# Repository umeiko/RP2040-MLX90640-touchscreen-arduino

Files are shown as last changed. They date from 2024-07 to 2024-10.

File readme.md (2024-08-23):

## RP2040热成像计划

电路图可以在[这里找到](https://oshwhub.com/umekoko/re-cheng-xiang_copy)

上位机成像在[这里](https://github.com/umeiko/Thermal-Imaging-Receiver)
- RP2040双核MCU + ST7789屏幕（240 * 280）物理分辨率 + CST816T 触摸IC + MLX90640热成像传感器。
- 引出了UART1，以及 SWD 调试接口。
- 可连接上位机图传。
- 集成卡尔曼滤波算法。

94acdedc4a31000fca7f8e9933caeeaf1839720

3a3f02000d5065bd46c5adb85640058

- 提供了热成像代码，位于`thermal_app`中。
- 提供lvgl示例代码，位于`lvgl_rp2040_example`中。
### 配置环境
- 配置 arduino-pico环境，具体可参考[arduino-pico](https://github.com/earlephilhower/arduino-pico/tree/master)仓库。
- Arduino按照如下参数配置开发板



- 配置好 `TFT_eSPI`屏幕驱动库，版本为`2.5.43`，具体可参考[TFT_eSPI](https://github.com/Bodmer/TFT_eSPI/tree/master)仓库。
- 将`C:\Users\*你自己的名字*\Documents\Arduino\libraries\TFT_eSPI\User_Setup.h`中替换成以下内容：

    ```C
    // ST7789 240 x 280 display with no chip select line
    #define USER_SETUP_ID 18
    #define ST7789_DRIVER 

    #define TFT_WIDTH  240
    #define TFT_HEIGHT 280

    #define CGRAM_OFFSET      // Library will add offsets required
    #define TFT_RGB_ORDER TFT_RGB  // Colour order Red-Green-Blue

    #define TFT_CS 9   // CS
    #define TFT_DC 8   // RX
    #define TFT_RST -1  // No Reset pin
    #define TFT_MOSI 7  // TX
    #define TFT_SCLK 6  // SCK

    #define LOAD_GLCD   
    #define LOAD_FONT2  
    #define LOAD_FONT4 
    #define LOAD_FONT6  
    #define LOAD_FONT7  
    #define LOAD_FONT8  
    #define LOAD_GFXFF  

    #define SMOOTH_FONT
    #define RP2040_PIO_SPI
    #define RP2040_DMA
    #define SPI_FREQUENCY  40000000
    #define SUPPORT_TRANSACTIONS
    ```
- 直接编译上传即可。

## 有问题发ISSUE

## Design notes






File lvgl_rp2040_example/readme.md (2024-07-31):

## LVGL示例

3a3f02000d5065bd46c5adb85640058

### 配置环境
- 配置 arduino-pico环境，具体可参考[arduino-pico](https://github.com/earlephilhower/arduino-pico/tree/master)仓库。
- 配置好 `TFT_eSPI`屏幕驱动库，版本为`2.5.43`，具体可参考[TFT_eSPI](https://github.com/Bodmer/TFT_eSPI/tree/master)仓库。
- 配置好 `lvgl`库，版本为`8.3.11`，具体可参考[lvgl](https://github.com/lvgl/lvgl)仓库。
- 将`C:\Users\*你自己的名字*\Documents\Arduino\libraries\TFT_eSPI\User_Setup.h`中替换成以下内容：

    ```C
    // ST7789 240 x 280 display with no chip select line
    #define USER_SETUP_ID 18
    #define ST7789_DRIVER 

    #define TFT_WIDTH  240
    #define TFT_HEIGHT 280

    #define CGRAM_OFFSET      // Library will add offsets required
    #define TFT_RGB_ORDER TFT_RGB  // Colour order Red-Green-Blue

    #define TFT_CS 9   // CS
    #define TFT_DC 8   // RX
    #define TFT_RST -1  // No Reset pin
    #define TFT_MOSI 7  // TX
    #define TFT_SCLK 6  // SCK

    #define LOAD_GLCD   
    #define LOAD_FONT2  
    #define LOAD_FONT4 
    #define LOAD_FONT6  
    #define LOAD_FONT7  
    #define LOAD_FONT8  
    #define LOAD_GFXFF  

    #define SMOOTH_FONT
    #define RP2040_PIO_SPI
    #define RP2040_DMA
    #define SPI_FREQUENCY  40000000
    #define SUPPORT_TRANSACTIONS
    ```
- 将`lv_conf.h`复制到`C:\Users\*你自己的名字*\Documents\Arduino\libraries\`中：
- 直接编译上传即可。

## 有问题发ISSUE

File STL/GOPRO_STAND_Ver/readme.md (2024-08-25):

UW3S @896RI19@5J@LE5`77

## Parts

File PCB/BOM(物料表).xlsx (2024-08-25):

名称 | 数量 | 型号 | 备注 | 购买链接
1K | 4 |  |  | 原装正品0603贴片电阻 1K 标字102 1/10W 精度5% （200只）-淘宝网 (taobao.com) (https://item.taobao.com/item.htm?id=522573302192)
10K | 1 |  |  | 原装正品 0603贴片电阻 10K 标字103 1/10W 精度5% （200只）-淘宝网 (taobao.com) (https://item.taobao.com/item.htm?id=522577284045)
5.1K | 2 |  |  | 原装正品 0603贴片电阻 5.1K 标字512 1/10W 精度5% （200只）-淘宝网 (taobao.com) (https://item.taobao.com/item.htm?id=522573158369&from=cart)
30K | 3 |  |  | 原装正品 0603贴片电阻 30K 标字303 1/10W 精度5% （200只）-淘宝网 (taobao.com) (https://item.taobao.com/item.htm?id=522554259377&from=cart)
51K | 1 |  |  | 原装正品 0603贴片电阻 51K 标字513 1/10W 精度5% （200只）-淘宝网 (taobao.com) (https://item.taobao.com/item.htm?id=522573274162&from=cart)
6.2R | 2 |  |  | 原装正品 0603贴片电阻 6.2R 6.2欧 1/10W 精度±1% （50只）-淘宝网 (taobao.com) (https://item.taobao.com/item.htm?id=525742588948&from=cart)
680K | 1 |  |  | 原装正品 0603贴片电阻 680K 标字684 1/10W 精度5% （200只）-淘宝网 (taobao.com) (https://item.taobao.com/item.htm?id=522573049867&from=cart)
300K | 3 |  |  | 原装正品 0603贴片电阻 300K 标字304 1/10W 精度5% （200只）-淘宝网 (taobao.com) (https://item.taobao.com/item.htm?id=522573437154&from=cart)
22uF | 2 |  |  | 原装0603贴片电容22uF(226)±20% 6.3V X5R CL10A226MQ8NRNE 50只-淘宝网 (taobao.com) (https://item.taobao.com/item.htm?id=626906975873&from=cart)
100nF | 5 |  |  | 0603贴片电容 104P 50V（0.1UF) 100NF 精度±10%（200只）-淘宝网 (taobao.com) (https://item.taobao.com/item.htm?id=522573286298&from=cart)
10uF | 2 |  |  | 原装正品0603贴片电容 10V 10UF ±10% X5R CL10A106KP8NNNC 50只-淘宝网 (taobao.com) (https://item.taobao.com/item.htm?id=537669338432&from=cart)
1uF | 1 |  |  | 【优信电子】0603贴片电容 105M（1UF) 16V 精度±20% (200只）-淘宝网 (taobao.com) (https://item.taobao.com/item.htm?id=522577340017&from=cart)
12pF | 2 |  |  | 原装 0603贴片电容 12pF(120) ±5% 50V NP0 CC0603JRNPO9BN120-淘宝网 (taobao.com) (https://item.taobao.com/item.htm?id=635779002557&from=cart)
10uH | 1 |  |  | 【优信电子】0805贴片电感 10UH ±10% EBLS2012-100K（20只）-淘宝网 (taobao.com) (https://item.taobao.com/item.htm?id=522573385027&from=cart)
4.7uH | 1 |  |  | 252012贴片 4.7uH ±20% SWPA252012S4R7MT 线绕SMD功率电感（5只-淘宝网 (taobao.com) (https://item.taobao.com/item.htm?id=588241056219&from=cart)
MLX90640传感器 | 1 |  |  | 原装正品MLX90640ESF-BAB-000-TU 热敏式图像传感器32x24红外阵列-淘宝网 (taobao.com) (https://item.taobao.com/item.htm?id=672821214850)
AO3401 | 2 |  |  | 贴片 AO3401 SOT-23 MOS管/三极管/场效应管 2.8A（20只）-淘宝网 (taobao.com) (https://item.taobao.com/item.htm?id=522554663865&from=cart)
AO3400 | 1 |  |  | 贴片 AO3400 SOT-23 MOS场效应管 2.5A（20只）-淘宝网 (taobao.com) (https://item.taobao.com/item.htm?id=522574089119&from=cart)
TypeC | 1 |  |  | 全铜 Type-C 3.1插座 16P 沉板1.6/0.8 USB-3.1母座 数据接口-淘宝网 (taobao.com) (https://item.taobao.com/item.htm?id=591365246153&from=cart&skuId=4230575123956)
FPC | 1 | 0.5-1.0H-18P 后翻盖镀金 |  | FFC/FPC连接器0.5-1.0H-4/5/6/8/10/12-40P后翻盖镀金间距0.5mm-淘宝网 (taobao.com) (https://item.taobao.com/item.htm?id=735834856054&from=cart&skuId=5084031056238)
充电芯片 | 1 |  |  | 原装正品 SGM4056-6.8YTDE8G/TR 丝印SG7 TDFN8 锂电池充电管理IC-淘宝网 (taobao.com) (https://item.taobao.com/item.htm?id=584245783298&from=cart)
LED | 1 |  |  | 原装正品 0805贴片LED灯 高亮白色 白光发光二极管正白光（20只）-淘宝网 (taobao.com) (https://item.taobao.com/item.htm?id=522572874608&from=cart)
RP2040 | 1 |  |  | 原装正品 RP2040 LQFN-56 ARM Cortex-M0 133MHz 微控制器芯片-淘宝网 (taobao.com) (https://item.taobao.com/item.htm?id=704705278044)
Flash | 1 |  |  | 原装正品 贴片 W25Q16JVUXIQ UFDFN-8 3V 16M-bit串行闪存芯片-淘宝网 (taobao.com) (https://item.taobao.com/item.htm?id=671657134105)
12Mhz | 1 | 12M 2016无源晶振 4脚 |  | 2016贴片无源晶振12M 16M20M24M25M26M27M32M40M50M19.2M 38.4MHZ-tmall.com天猫 (https://detail.tmall.com/item.htm?id=611704538306&from=cart&skuId=4304314032761)
DCDC | 1 | SGM6036-3.3YUDT6G/TR UTDFN |  | 原装SGM6036-3.3YUDT6G/TR SGM6031-ADJYUDT6G/TR UTDFN贴片-淘宝网 (taobao.com) (https://item.taobao.com/item.htm?id=714214021196&from=cart&skuId=5000729821152)
按钮 | 3 | 2*4*3.5（小侧按） |  | 包邮 轻触开关 侧按键 2*4*3.5/3*6*3.5 小侧按/大侧按 贴片 微动-淘宝网 (taobao.com) (https://item.taobao.com/item.htm?id=740684741262&from=cart&skuId=5282210427438)
触屏模组 | 1 | P169H002-CTP 带电容触摸 |  | 1.69寸全视角IPSTFT彩屏液晶显示屏SPI4L接口ST7789V电容屏触摸屏-淘宝网 (taobao.com) (https://item.taobao.com/item.htm?id=679828186292&from=cart&skuId=5044706070761)
拨片开关 | 1 | SSAJ120100 |  | 日本ALPS SSAJ120100 小薄型拨动开关5脚2档 滑动推进开关 贴片-淘宝网 (taobao.com) (https://item.taobao.com/item.htm?id=641266818120&_u=1uprguofc12)
602530电池 | 1 | 乳白色 602530/500毫安 |  | 602530智能定位儿童电话手表电池3.7V锂电池5V聚合物大容量500mAh-淘宝网 (taobao.com) (https://item.taobao.com/item.htm?id=643350021642&from=cart&skuId=4807232935323)
PCB | 1 |  | 1.6厚度 | rp2040+MLX90640触屏迷你热成像仪 - 嘉立创EDA开源硬件平台 (oshwhub.com) (https://oshwhub.com/umekoko/re-cheng-xiang_copy)
M1.4螺丝 | 4 | M1.4*5 [200只] | 固定PCB | 304不锈钢十字圆头螺丝钉PM盘头螺栓机丝螺钉M1/M1.2/M1.4/M1.6M2 (https://item.taobao.com/item.htm?id=40012193346&from=cart&skuId=5094465275721)
M5*20螺丝 | 1 | M5*20 [20只] | GPRO兼容支架 | 304不锈钢十字圆头螺丝钉PM盘头螺栓机丝螺钉M1/M1.2/M1.4/M1.6M2 (https://item.taobao.com/item.htm?id=40012193346&from=cart&skuId=4814043237375)
M2*5螺丝 | 1 | M2*5 [200只] | GPRO兼容支架 | 304不锈钢十字圆头螺丝钉PM盘头螺栓机丝螺钉M1/M1.2/M1.4/M1.6M2 (https://item.taobao.com/item.htm?id=40012193346&from=cart&skuId=5094465275713)
M3*12螺丝 | 1 | M3*12 [100只] | GPRO兼容支架 | 304不锈钢十字圆头螺丝钉PM盘头螺栓机丝螺钉M1/M1.2/M1.4/M1.6M2 (https://item.taobao.com/item.htm?id=40012193346&from=cart&skuId=4814041545641)

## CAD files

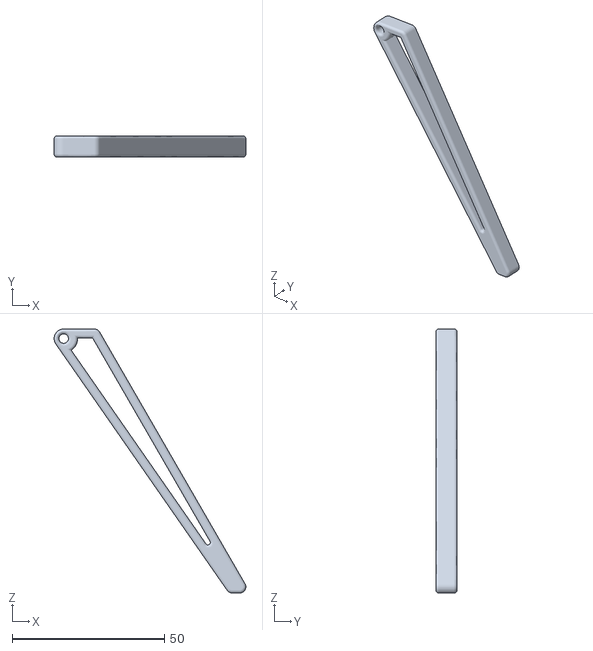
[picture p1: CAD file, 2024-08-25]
STL/GOPRO_STAND_Ver/GO_PRO_TripodLeg_x3.stl
62.9 x 7.00 x 86.6

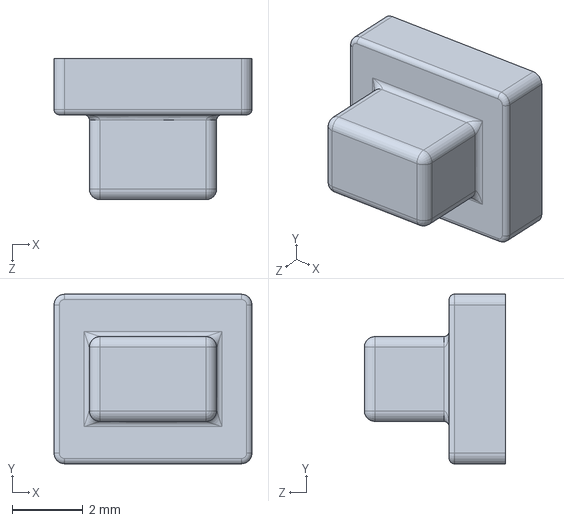
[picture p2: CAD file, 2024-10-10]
STL/on-off-button.SLDPRT
5.60 x 4.80 x 4.00 mm

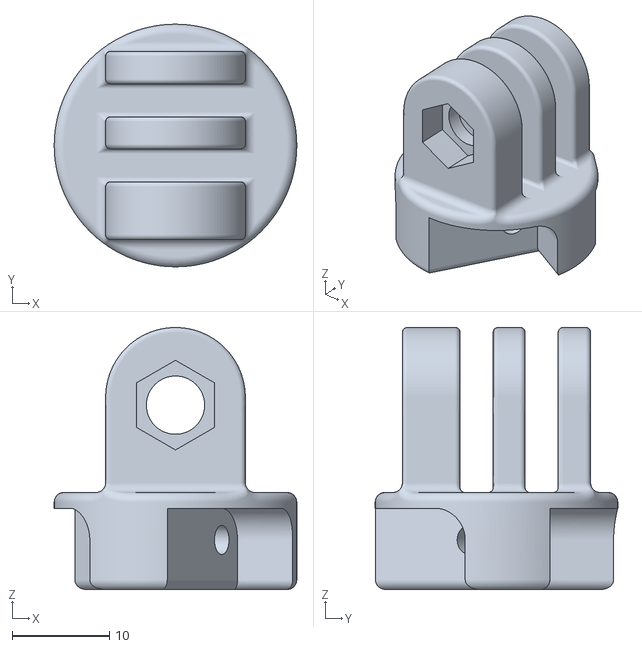
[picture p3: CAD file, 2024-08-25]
STL/GOPRO_STAND_Ver/GO_PRO_TripodHead_x1.stl
25.0 x 25.0 x 27.0

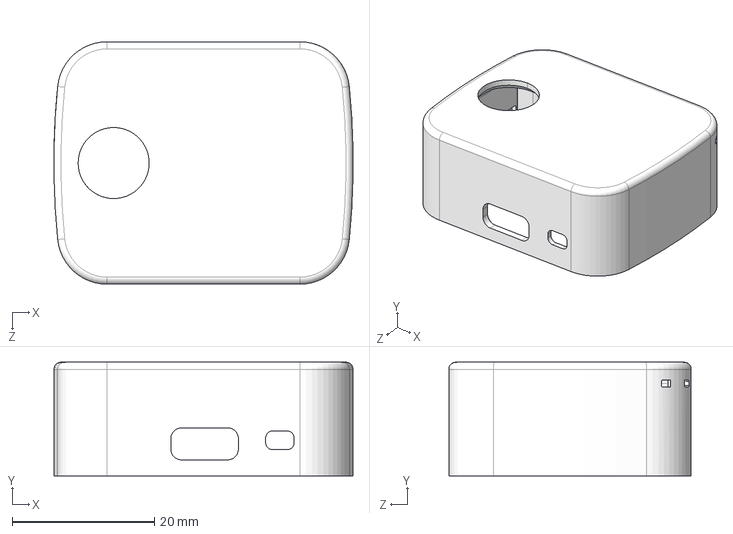
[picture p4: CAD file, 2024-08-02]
STL/shell2040.STEP
42.1 x 16.0 x 34.1 mm

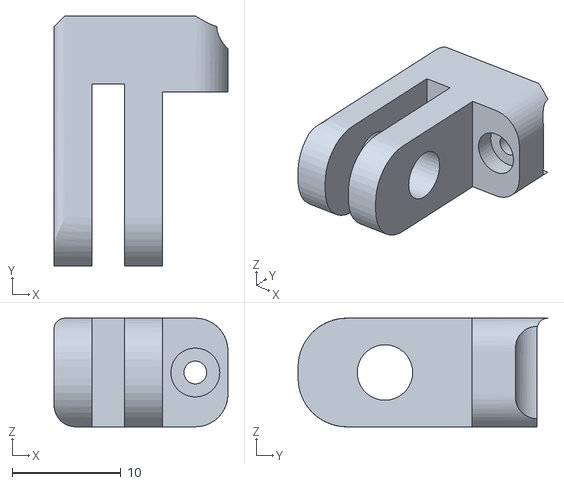
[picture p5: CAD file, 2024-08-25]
STL/GOPRO_STAND_Ver/TransRing_x1.STL
16.0 x 23.0 x 10.0

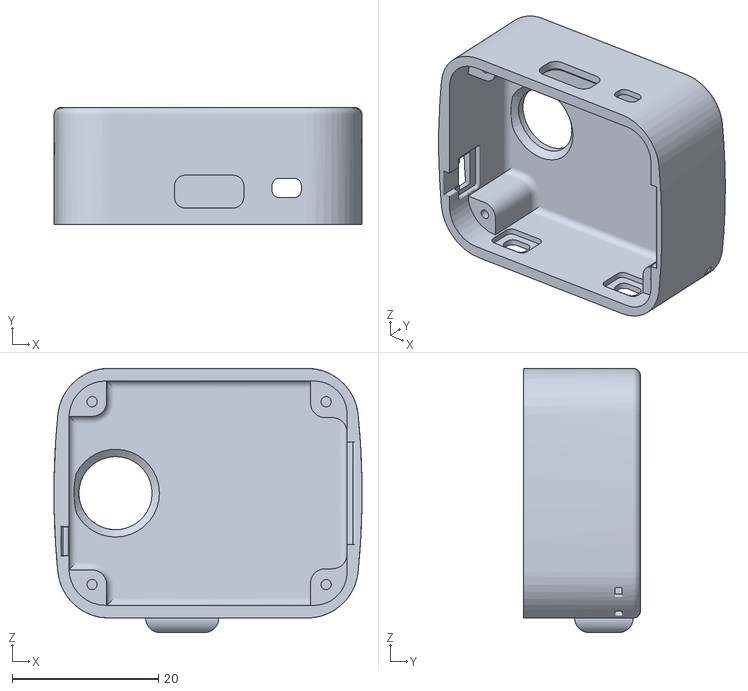
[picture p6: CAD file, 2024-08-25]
STL/GOPRO_STAND_Ver/shell_GOPRO_comp_x1.STL
42.1 x 16.0 x 36.1

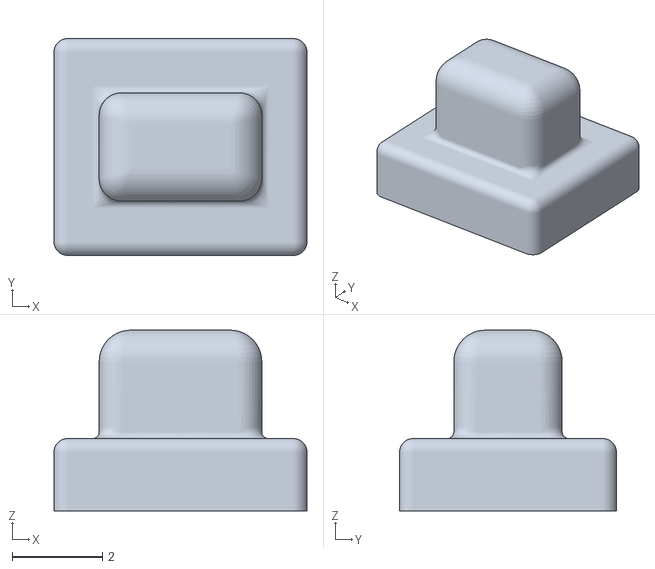
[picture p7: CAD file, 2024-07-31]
STL/switch_x1.STL
5.60 x 4.80 x 4.00

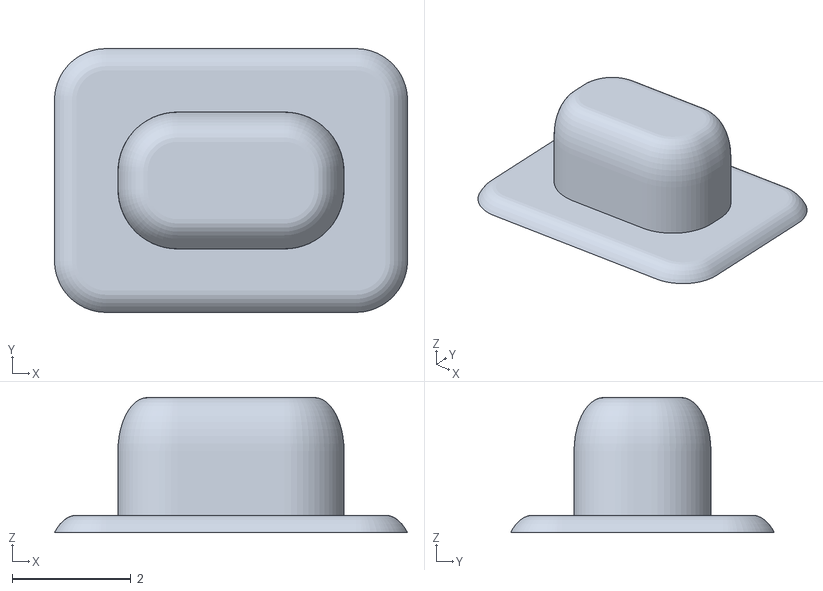
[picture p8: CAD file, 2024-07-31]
STL/GOPRO_STAND_Ver/button_x3.stl
5.93 x 4.43 x 2.27

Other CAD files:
STL/shell.STL
STL/GOPRO_STAND_Ver/switch_x1.STL

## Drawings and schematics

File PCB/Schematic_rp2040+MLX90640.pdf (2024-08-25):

复位
晶振

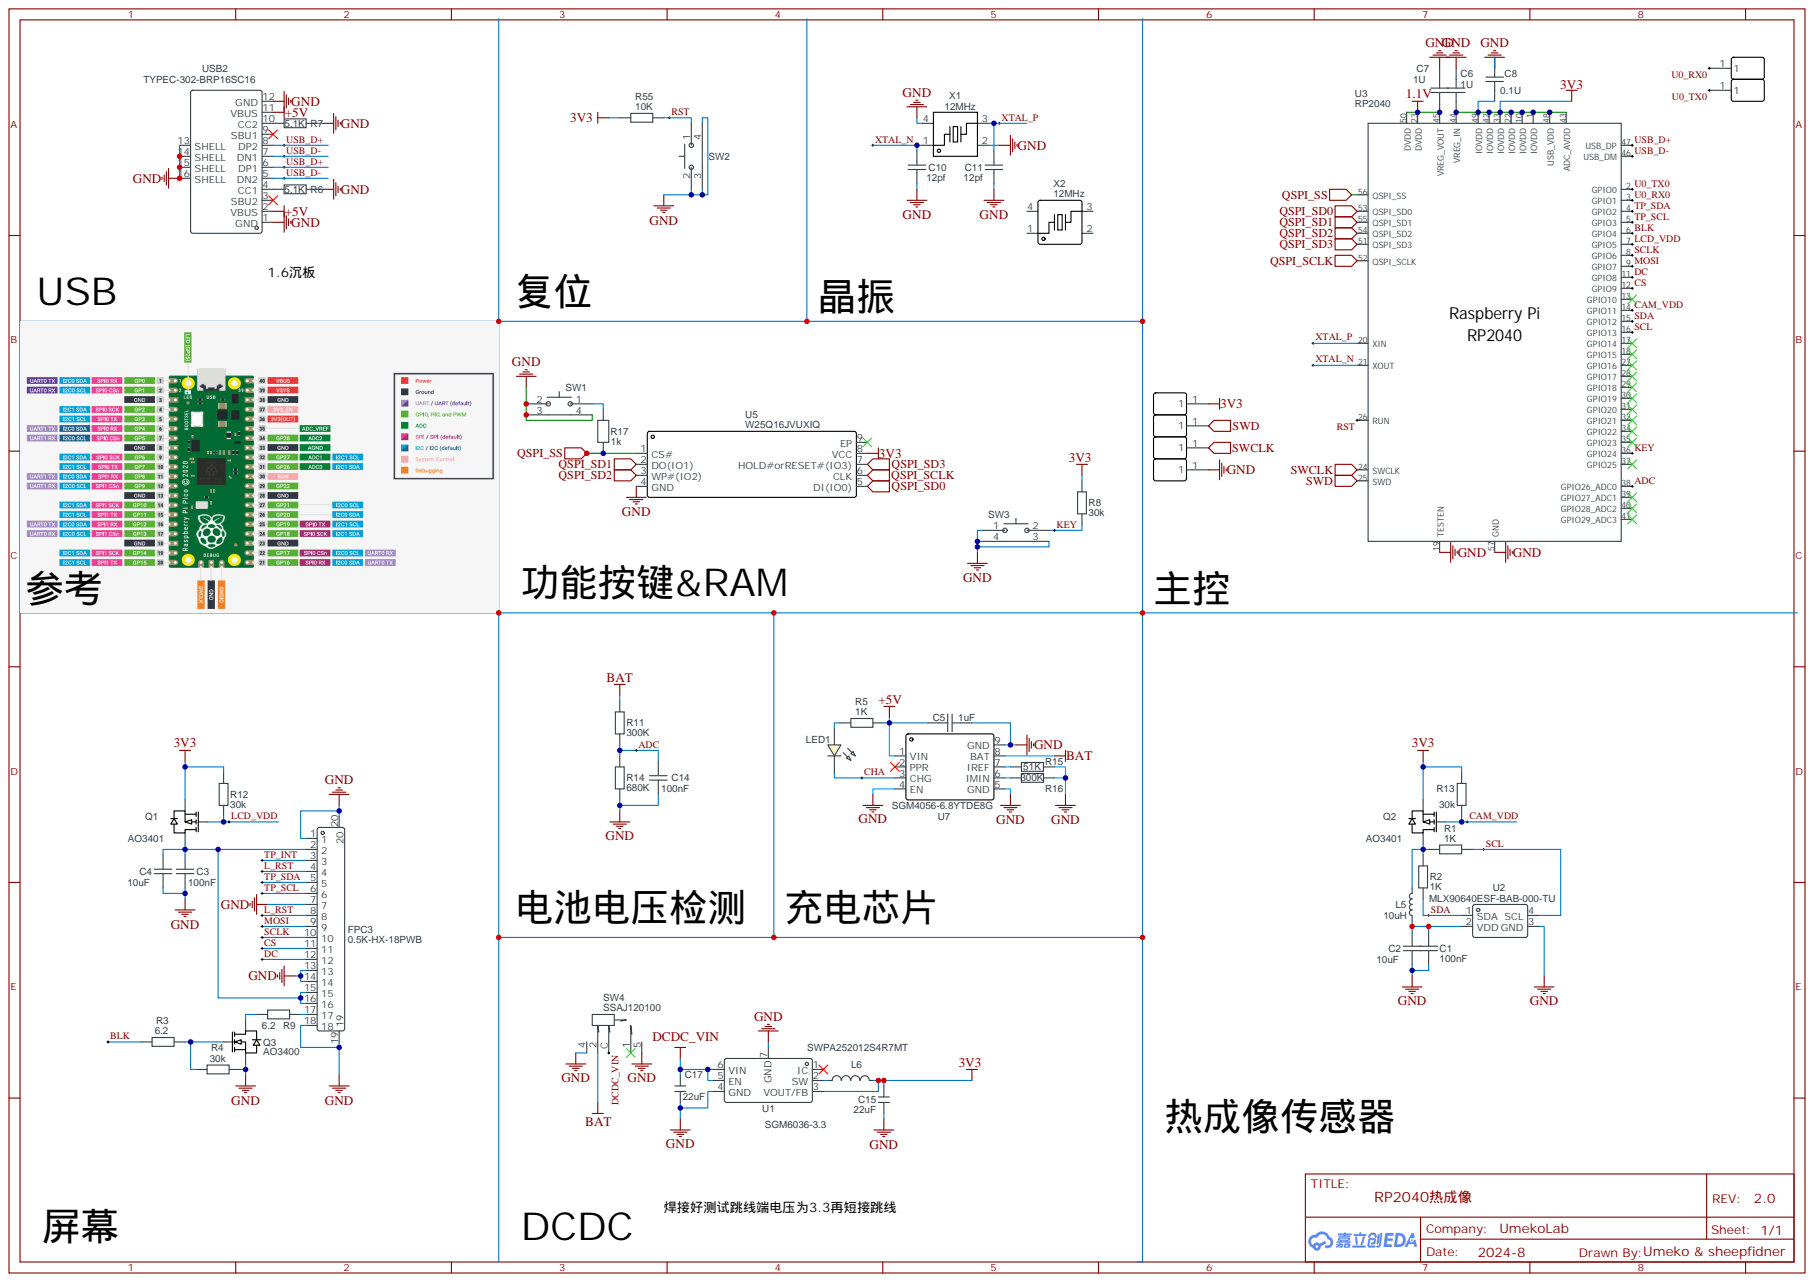
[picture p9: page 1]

SHELL 16 SHELL 15 SHELL 14 SHELL 13

Drawn By:Umeko & sheepfidner

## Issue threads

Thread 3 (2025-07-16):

修正电池电压采样条件，避免快速跳变问题

BoyceXX, 2025-07-16:
描述：
当前代码中电池电压采样的条件写成了：

if (xStartTime + xWait > xTaskGetTickCount()) {
    adc_value = analogRead(BAT_ADC);
    bat_v = (float)adc_value / 1024. * 3.3 * coef;
    xStartTime = xTaskGetTickCount();
}

该条件导致采样逻辑反向，频繁更新电压值，造成GUI上的电压显示快速跳变。

建议修改为：

if (xTaskGetTickCount() > xStartTime + xWait) {
    adc_value = analogRead(BAT_ADC);
    bat_v = (float)adc_value / 1024.0 * 3.3 * coef;
    xStartTime = xTaskGetTickCount();
}

这样能确保每隔固定时间间隔才采样一次，电压显示更稳定。

umeiko, 2025-08-02:
感谢您的指出，欢迎pr，请将此issue关联到您的pr

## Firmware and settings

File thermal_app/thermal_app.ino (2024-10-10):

/*
 Huge thank you to Uspizig for offering this library that I have modified for TFT_eSPI: https://github.com/Uspizig/MLX90640
 Has to be Library, TFT_eSPI Rev 2.5.43
 The latest does not work

*/
#include <Arduino.h>
#include <FreeRTOS.h>
#include <task.h>
#include <TFT_eSPI.h> 
#include <SPI.h>
#include <Wire.h>
#include <EEPROM.h>

#include "pico/stdlib.h"
#include "hardware/rtc.h"
#include "hardware/pll.h"
#include "hardware/clocks.h"
#include "hardware/xosc.h"
// #include "hardware/rosc.h"
#include "hardware/regs/io_bank0.h"
// For __wfi
#include "hardware/sync.h"
// For scb_hw so we can enable deep sleep
#include "hardware/structs/scb.h"


#include "MLX90640_API.h"
#include "MLX90640_I2C_Driver.h"
#include "CST816T.h"
#include "kalman_filter.h"
#include "BilinearInterpolation.h"

#define TA_SHIFT 8 //Default shift for MLX90640 in open air
#define MLX_VDD  11
#define MLX_SDA  12
#define MLX_SCL  13

#define TOUCH_SDA 2
#define TOUCH_SCL 3
#define TOUCH_RST -1

#define BAT_ADC  26
#define SCREEN_BL_PIN 4
#define SCREEN_VDD 5

#define SCREEN_ROTATION 1
#define CURSOR_SIZE 2

// #define DRAW_BLOCKS // 使用方块来绘制热力图
// #define DRAW_PIXELS  // 使用像素来绘制
#define DRAW_PIXELS_DMA  // 使用DMA来绘制

#define KALMAN  // 使用 卡尔曼滤波器
// #define SERIAL1_DEBUG  


#if defined(KALMAN)
#include "kalman_filter.h"
const static float init_P = 0.1;
const static float init_G = 0.0;
const static float init_O = 26;

static KFPTypeS kfpVar3Array[768];  // 卡尔曼滤波器变量数组
// 初始化卡尔曼滤波器数组的函数
void KalmanArrayInit() {
    // 循环遍历数组中的每个元素
    for (int i = 0; i < 768; ++i) {
        // 初始化每个元素
        kfpVar3Array[i] = (KFPTypeS){
         init_P,     //估算协方差. 初始化值为 0.02
         init_G,     //卡尔曼增益. 初始化值为 0
         init_O    //卡尔曼滤波器输出. 初始化值为 0
        };
    }
}

#endif

#define _SCALE 9
#define BTN_LONG_PUSH_T 1000
#define TOUCH_LONG_PUSH_T 200
#define uS_TO_S_FACTOR 1000000ULL  /* Conversion factor for micro seconds to seconds */
#define TIME_TO_SLEEP  5        /* Time ESP32 will go to sleep (in seconds) */


const int buttonPin1 = 24;
const int buttonPin2 = -1; 


bool buttonState1 = 1;  
bool buttonState2 = 1;  

const byte MLX90640_address = 0x33;
static float mlx90640To[768];              // 从MLX90640读取的温度数据
static int mlx90640To_buffer[768];       // 缓存区域，复制MLX90640读取的温度数据并用于绘制热力图
static float mlx90640To_send_buffer[768];  // 缓存区域，复制MLX90640读取的温度数据，用于发送到上位机
static uint8_t* mlx90640To_Serial_buffer = (uint8_t*)mlx90640To_send_buffer;  



paramsMLX90640 mlx90640;

#if defined(DRAW_PIXELS)
static uint16_t heat_bitmap[32*_SCALE * 24*_SCALE] = {}; // rgb56556形式的内存，用于存储要渲染的图像
#endif

uint16_t test_points[5][2];
int brightness = 100;

int R_colour, G_colour, B_colour;            
// int i, j;                                    
float T_max, T_min, T_avg;                            
float T_center;  
int max_x, max_y, min_x, min_y;

float bat_v;

bool lock = false;  // 简单的锁，防止拷贝温度数据的时候对内存的访问冲突
bool serial_cp_lock = false;  // 简单的锁，防止拷贝温度数据的时候对内存的访问冲突
bool touch_updated = false;
bool mlx_is_connected = false;

bool power_on = true;  // 是否开机
bool freeze = false;  // 暂停画面
bool show_local_temp_flag = true;  // 是否显示点测温
bool clear_local_temp = false;     // 点测温清除

bool use_upsample = true;  // 是否上采样

TFT_eSPI tft = TFT_eSPI();  
CST816T touch(TOUCH_SDA, TOUCH_SCL, TOUCH_RST, -1);	// sda, scl, rst, irq

int diffx, diffy;

// ===============================
// ===== determine the colour ====
// ===============================
void getColour(int j)
   {
    if (j >= 0 && j < 30)
       {
        R_colour = 0;
        G_colour = 0;
        B_colour = 20 + 4 * j;
       }
    
    if (j >= 30 && j < 60)
       {
        R_colour = 4 * (j - 30);
        G_colour = 0;
        B_colour = 140 - 2 * (j - 30);
       }

    if (j >= 60 && j < 90)
       {
        R_colour = 120 + 4 * (j - 60);
        G_colour = 0;
        B_colour = 80 - 2 * (j - 60);
       }

    if (j >= 90 && j < 120)
       {
        R_colour = 255;
        G_colour = 0 + 2 * (j - 90);
        B_colour = 10 - (j - 90) / 3;
       }

    if (j >= 120 && j < 150)
       {
        R_colour = 255;
        G_colour = 60 + 175 * (j - 120) / 30;
        B_colour = 0;
       }

    if (j >= 150 && j <= 180)
       {
        R_colour = 255;
        G_colour = 235 + (j - 150) * 20 / 30;
        B_colour = 0 + 85 * (j - 150) / 10;
       }
}

void print_bitmap(int x, int y, uint16_t * data){
   
   for(int i=0; i<y; i++){
      for(int j=0; j<x; j++){
         Serial.print(data[i*j]);
         Serial.print(" ");
      }
      Serial.print("\n");
   }
   Serial.print("\n\n");
}

//Returns true if the MLX90640 is detected on the I2C bus
boolean isConnected()
   {
    Wire.beginTransmission((uint8_t)MLX90640_address);
    if (Wire.endTransmission() != 0){return (false);}
    return (true);
   }   

// 绘制十字
void draw_cross(int x, int y, int len){
   tft.drawLine(x - len/2, y, x + len/2, y, tft.color565(255, 255, 255));
   tft.drawLine(x, y-len/2, x, y+len/2,  tft.color565(255, 255, 255));

   tft.drawLine(x - len/4, y, x + len/4, y, tft.color565(0, 0, 0));
   tft.drawLine(x, y-len/4, x, y+len/4,  tft.color565(0, 0, 0));
}

// 点测温功能
void show_local_temp(int x, int y){
   draw_cross(x, y, 10);
   float temp_xy = mlx90640To[(24 - y / _SCALE) * 32 + (x / _SCALE)];
   int shift_x, shift_y;
   if (x<140){shift_x=10;} else {shift_x=-40;}
   if (y<120){shift_y=10;} else {shift_y=-10;}
   tft.setTextSize(CURSOR_SIZE);
   tft.setCursor(x+shift_x, y+shift_y);
   tft.printf("%.2f", temp_xy);
}  

#if defined(DRAW_BLOCKS)
void draw_heat_image(bool re_mapcolor=true){
   tft.setRotation(3);
   for (int i = 0 ; i < 24 ; i++){
   for (int j = 0; j < 32; j++){
      if (re_mapcolor) {mlx90640To_buffer[i*32 + j] = 180.0 * (mlx90640To_buffer[i*32 + j] - T_min) / (T_max - T_min);}
      getColour(mlx90640To_buffer[i*32 + j]);
      tft.fillRect(280 - j * _SCALE, (240 - _SCALE * 24) + i * _SCALE, _SCALE, _SCALE, tft.color565(R_colour, G_colour, B_colour));  
      // tft.drawBitmap();
      }
   }
   tft.setRotation(SCREEN_ROTATION);
}
#endif


#if defined(DRAW_PIXELS)
// 在一块图像内存上绘制一个同色的方块
void draw_block_bitmap(int x, int y, int w, int max_x, int max_y, uint16_t color, uint16_t* data){
   for(int i =y; i < y + w; i++){
        for(int j = x; j < x + w; j++){
         data[i * max_x + j] = color;
      }
   }
}

// 更新图像内存中的图像
void update_bitmap(bool re_mapcolor=true){
   for(int y=0; y<24; y++){ 
      for(int x=0; x<32; x++){
         int id = (23-y) * 32 + x;
         if (re_mapcolor) {mlx90640To_buffer[id] = 180.0 * (mlx90640To_buffer[id] - T_min) / (T_max - T_min);}
         getColour(mlx90640To_buffer[id]);
         // draw_block_bitmap(x*_SCALE, y*_SCALE, _SCALE, 32*_SCALE, 24*_SCALE, tft.color565(255, 0, 0), heat_bitmap);
         draw_block_bitmap(x*_SCALE, y*_SCALE, _SCALE, 32*_SCALE, 24*_SCALE, tft.color565(R_colour, G_colour, B_colour), heat_bitmap);
      } 
   }
}

void update_bitmap_bio_linear(){
   int value;
   for(int y=0; y<24 * _SCALE; y++){ 
      for(int x=0; x<32 * _SCALE; x++){
         value = bio_linear_interpolation(x, y, mlx90640To_buffer);
         getColour(value);
         heat_bitmap[y * 32 * _SCALE + x] = tft.color565(R_colour, G_colour, B_colour);
      }
   }
}

// 在屏幕上绘制热力图
void draw_heat_image(bool re_mapcolor=true){
   // tft.setRotation(3);
   tft.setRotation(SCREEN_ROTATION);
   if(re_mapcolor){
      update_bitmap_bio_linear();
   }
   tft.pushImage(0, 0, 32*_SCALE, 24*_SCALE, heat_bitmap);
}
#endif


#if defined(DRAW_PIXELS_DMA)
const int lines = 25;
uint16_t  lineBuffer[32 * _SCALE * lines]; // Toggle buffer for lines
uint16_t  dmaBuffer1[32 * _SCALE * lines]; // Toggle buffer for lines
uint16_t  dmaBuffer2[32 * _SCALE * lines]; // Toggle buffer for lines
uint16_t* dmaBufferPtr = dmaBuffer1;
bool dmaBufferSel = 0;
// 在屏幕上绘制热力图
void draw_heat_image(bool re_mapcolor=true){  
   static int value;
   static int now_y = 0;
   tft.setRotation(SCREEN_ROTATION);
   if(use_upsample){
      tft.startWrite();
      for(int y=0; y<24 * _SCALE; y++){ 
         for(int x=0; x<32 * _SCALE; x++){
            value = bio_linear_interpolation(x, y, mlx90640To_buffer);
            getColour(value);
            lineBuffer[x + now_y*32 * _SCALE] = tft.color565(R_colour, G_colour, B_colour);
         }
         now_y ++;
         if(now_y==lines){
            if (dmaBufferSel) dmaBufferPtr = dmaBuffer2;
            else dmaBufferPtr = dmaBuffer1;
            dmaBufferSel = !dmaBufferSel; // Toggle buffer selection
            // tft.startWrite();
            tft.pushImageDMA(0, y-now_y, 32*_SCALE, lines, lineBuffer, dmaBufferPtr);
            // tft.endWrite();
            now_y = 0;
         }
      }if(now_y!=0){
         if (dmaBufferSel) dmaBufferPtr = dmaBuffer2;
         else dmaBufferPtr = dmaBuffer1;
         dmaBufferSel = !dmaBufferSel; // Toggle buffer selection
         // tft.startWrite();
         tft.pushImageDMA(0, 24*_SCALE-1-now_y, 32*_SCALE, now_y, lineBuffer, dmaBufferPtr);
         // tft.endWrite();
         now_y = 0;
      }
      tft.endWrite();
   }else{
      tft.setRotation(3);
      for (int i = 0 ; i < 24 ; i++){
      for (int j = 0; j < 32; j++){
         // if (re_mapcolor) {mlx90640To_buffer[i*32 + j] = 180.0 * (mlx90640To_buffer[i*32 + j] - T_min) / (T_max - T_min);}
         getColour(mlx90640To_buffer[i*32 + j]);
         tft.fillRect(280 - j * _SCALE, (240 - _SCALE * 24) + i * _SCALE, _SCALE, _SCALE, tft.color565(R_colour, G_colour, B_colour));  
      }
      }
   }
}

#endif

int status;
uint16_t eeMLX90640[832];
int mlx_setup(){
   pinMode(MLX_VDD, OUTPUT);
   digitalWrite(MLX_VDD, LOW);
   Wire.setSDA(MLX_SDA);
   Wire.setSCL(MLX_SCL);
   Wire.begin(); 
   vTaskDelay(500);
   Wire.setClock(800000); //Increase I2C clock speed to 800kHz
   Serial1.println("MLX90640 IR Array Example");
   mlx_is_connected = isConnected();
   if (mlx_is_connected == false){
      // while(!isConnected()){
         Serial1.println("MLX90640 not detected at default I2C address. Please check wiring.");
      // }
      return 1;
   }
   Serial1.println("MLX90640 online!");
   status = MLX90640_DumpEE(MLX90640_address, eeMLX90640);
   if (status != 0)
      Serial1.println("Failed to load system parameters");

   status = MLX90640_ExtractParameters(eeMLX90640, &mlx90640);
   if (status != 0)
   {
      Serial1.println("Parameter extraction failed");
      Serial1.print(" status = ");
      Serial1.println(status);
   }
   MLX90640_SetRefreshRate(MLX90640_address, 0x04); //Set rate to 4Hz effective - Works
   // MLX90640_I2CWrite(0x33, 0x800D, 6401);    // writes the value 1901 (HEX) = 6401 (DEC) in the register at position 0x800D to enable reading out the temperatures!!!
   MLX90640_SetRefreshRate(MLX90640_address, 0x05); //Set rate to 8Hz effective - Works at 800kHz
   return 0;
}

uint16_t count_retry = 0;
void mlx_loop(){
   if(!mlx_is_connected && count_retry < 10){
      mlx_setup();
      count_retry++;
   }
   if (!freeze && mlx_is_connected==true){ // 如果画面被暂停会跳过这个热成像图的刷新
      lock = true;
      for (byte x = 0 ; x < 2 ; x++){
         uint16_t mlx90640Frame[834];
         int status = MLX90640_GetFrameData(MLX90640_address, mlx90640Frame);
      
         if (status < 0){
            Serial1.print("GetFrame Error: ");
            Serial1.println(status);
            }
         float vdd = MLX90640_GetVdd(mlx90640Frame, &mlx90640);
         float Ta = MLX90640_GetTa(mlx90640Frame, &mlx90640);
         float tr = Ta - TA_SHIFT; //Reflected temperature based on the sensor ambient temperature
         float emissivity = 0.95;
         MLX90640_CalculateTo(mlx90640Frame, &mlx90640, emissivity, tr, mlx90640To);
      }

      // mlx90640To[229] = 0.5 * (mlx90640To[228] + mlx90640To[230]);    // eliminate the error-pixels
      // mlx90640To[428] = 0.5 * (mlx90640To[427] + mlx90640To[429]);    // eliminate the error-pixels
      
      T_min = mlx90640To[0];
      T_max = mlx90640To[0];
      T_avg = mlx90640To[0];
      for (int i = 1; i < 768; i++){
         if((mlx90640To[i] > -41) && (mlx90640To[i] < 301))
            {
               if(mlx90640To[i] < T_min)
                  {
                  T_min = mlx90640To[i];
                  }

               if(mlx90640To[i] > T_max)
                  {
                  T_max = mlx90640To[i];
                  max_x = i / 32;
                  max_y = i % 32;
                  }
            #if defined(KALMAN)
            mlx90640To[i] = KalmanFilter(&kfpVar3Array[i], mlx90640To[i]);
            #endif
            }
         else if(i > 0){
               mlx90640To[i] = mlx90640To[i-1];
            }
         else{
                mlx90640To[i] = mlx90640To[i+1];
            }
            T_avg = T_avg + mlx90640To[i];
         }
      T_avg = T_avg / 768;
      #if defined(KALMAN)
      T_avg = KalmanFilter(&kfpVar1, T_avg);
      T_max = KalmanFilter(&kfpVar2, T_max);
      T_min = KalmanFilter(&kfpVar3, T_min);
      #endif
      lock = false;
   }
}

// 热成像读取多任务
void task_mlx(void * ptr){
   mlx_setup();
   // MLX主循环
   for(;power_on==true;){
      mlx_loop();
      vTaskDelay(10);
   }
   vTaskDelete(NULL); 
}

// 关机
void power_off(){

//    esp_sleep_pd_config(ESP_PD_DOMAIN_RTC_PERIPH, ESP_PD_OPTION_OFF);
   for(int i=brightness; i>0; i--){
      analogWrite(SCREEN_BL_PIN, i);
      vTaskDelay(2);
   }
   
   power_on = false;
   digitalWrite(MLX_VDD, HIGH);
   analogWrite(SCREEN_BL_PIN, 0);
   digitalWrite(SCREEN_BL_PIN, LOW);
   vTaskDelay(2000);
   
   xosc_dormant();
//    sleep_run_from_xosc();
   // esp_light_sleep_start();
//    esp_deep_sleep_start();
   vTaskDelete(NULL); 
}

// 背光调节,会限制输入亮度在正确范围内
void set_brightness(int _brightness){
   if (_brightness < 255 && _brightness > 5){
      analogWriteFreq(10000);
      analogWrite(SCREEN_BL_PIN, _brightness);
      brightness = _brightness;
   }else if(_brightness >= 255){analogWrite(SCREEN_BL_PIN, 255); brightness=255;
   }else if(_brightness <= 5)   {analogWrite(SCREEN_BL_PIN, 5); brightness=5;
   }
}

void smooth_on(){
   pinMode(SCREEN_BL_PIN, OUTPUT);
   analogWrite(SCREEN_BL_PIN, 0);
   analogWriteFreq(10000);
   for(int i=0; i<brightness; i++){
      analogWrite(SCREEN_BL_PIN, i);
      vTaskDelay(2);
   }
}

// 平滑的开机
void task_smooth_on(void * ptr){
   smooth_on();
   vTaskDelete(NULL); 
}


uint32_t dt = millis();
void screen_setup(){
   tft.setRotation(SCREEN_ROTATION);
   tft.fillScreen(TFT_BLACK);
   // tft.fillScreen(TFT_GREEN);
   test_points[0][0] = 120;
   test_points[0][1] = 110;
   tft.setTextSize(0);
   tft.setCursor(25, 220);
   tft.printf("max: %.2f  ", T_max);
   tft.setCursor(25, 230);
   tft.printf("min: %.2f  ", T_min);

   tft.setCursor(105, 220);
   tft.printf("avg: %.2f  ", T_avg);
   tft.setCursor(105, 230);
   tft.printf("bat: %.2f v ", bat_v);

   tft.setCursor(180, 220);
   tft.printf("bright: %d  ", brightness);
   tft.setCursor(180, 230);
   tft.printf("time: %d ", dt);
   tft.printf("ms     ");
}
void screen_loop(){
   if (!freeze){ // 如果画面被暂停会跳过这个热成像图的刷新
   // 只有画面更新才会绘制一张热成像图
   dt = millis();
   while(lock && power_on){
      // 阻塞画面
      vTaskDelay(1);
   }
   for (int i = 0; i < 768; i++) {
      // mlx90640To_buffer[i] = mlx90640To[i];
      mlx90640To_buffer[i] = (int)(180.0 * (mlx90640To[i] - T_min) / (T_max - T_min));
   }  // 拷贝温度信息
   draw_heat_image();
   dt = millis() - dt;
   }else{dt = 0;}

   tft.setRotation(SCREEN_ROTATION);
   if (test_points[0][0]==0 && test_points[0][1]==0 ){}else{show_local_temp(test_points[0][0], test_points[0][1]);}
   if (clear_local_temp==true) {draw_heat_image(false); clear_local_temp=false;}

   tft.setRotation(SCREEN_ROTATION);
   tft.setTextColor(TFT_WHITE, TFT_BLACK); 
   tft.setTextSize(0);
   if (!mlx_is_connected){
      tft.setCursor(25, 110);
      tft.printf("MLX90640 not detected at default I2C address. Please check wiring.");
   }
   tft.setCursor(25, 220);
   tft.printf("max: %.2f  ", T_max);
   tft.setCursor(25, 230);
   tft.printf("min: %.2f  ", T_min);

   tft.setCursor(105, 220);
   tft.printf("avg: %.2f  ", T_avg);
   tft.setCursor(105, 230);
   tft.printf("bat: %.2f v ", bat_v);

   tft.setCursor(180, 220);
   tft.printf("bright: %d  ", brightness);
   tft.setCursor(180, 230);
   tft.printf("time: %d ", dt);
   tft.printf("ms     ");
   // vTaskDelay(10);
}

void task_screen_draw(void * ptr){
   screen_setup();
   for(;power_on==true;){
      screen_loop();
   }
   vTaskDelete(NULL);
}

// 通过串口传输单个浮点数据
void send_float_as_uint8(float f, uint8_t *buf) {
   memcpy(buf, &f, sizeof(float));
   Serial.write(buf, sizeof(float));
}

// 通过串口把整个温度数据矩阵传输
void send_to_serial() {
   // memcpy(mlx90640To_Serial_buffer, mlx90640To_send_buffer, 768 * sizeof(float));
   Serial.write(mlx90640To_Serial_buffer, 768 * sizeof(float));
}

void task_serial_communicate(void * ptr){
   vTaskDelay(3000);
   uint8_t send_buf[4];

   for(;power_on==true;){
      // 拷贝温度信息
      while (lock == true) {vTaskDelay(1);}
      memcpy(mlx90640To_send_buffer, mlx90640To, 768 * sizeof(float));
      // for (int i = 0; i < 768; i++) {mlx90640To_send_buffer[i] = mlx90640To[i];} 
      Serial.print("BEGIN");
      send_float_as_uint8(T_max, send_buf);
      send_float_as_uint8(T_min, send_buf);
      send_float_as_uint8(T_avg, send_buf);
      // for (int i = 0; i < 768; i++){
      //    send_float_as_uint8(mlx90640To_send_buffer[i], send_buf);
      //    if(i % 5==0){vTaskDelay(1);}
      // }
      send_to_serial();
      Serial.print("END");
      vTaskDelay(30);
   }
   vTaskDelete(NULL);
}



void setup1(void)
 {
   Serial.begin(115200);
   EEPROM.begin(128);
   uint8_t value = EEPROM.read(0);
   if (value != 0 && value != 1) {
      value = 0;  
   }
   use_upsample = value;
   brightness = EEPROM.read(1);
   #if defined(SERIAL1_DEBUG)
   Serial1.begin(115200);
   Serial1.println("RP2040 is starting...");
   #endif
   #if defined(KALMAN)
   KalmanArrayInit();
   #endif
   touch.begin();
//  mlx_setup();
   // 按钮启用
   pinMode(SCREEN_BL_PIN, OUTPUT);
   digitalWrite(SCREEN_BL_PIN, LOW);
   pinMode(SCREEN_VDD, OUTPUT);
   digitalWrite(SCREEN_VDD, LOW);
   // xTaskCreate(task_mlx, "MLX_FLASHING", 1024 * 4, NULL, 1, NULL);
//  xTaskCreate(task_bat, "BAT_MANAGER", 1024 * 2, NULL, 3, NULL);
   tft.init();
   tft.setSwapBytes(true);
   tft.initDMA();
   screen_setup();
   vTaskDelay(300);
   smooth_on();
}

void loop1() 
{
   screen_loop();
}
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
void loop() 
{
   vTaskDelay(3000);
}

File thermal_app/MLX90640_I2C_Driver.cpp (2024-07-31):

/**
   @copyright (C) 2017 Melexis N.V.

   Licensed under the Apache License, Version 2.0 (the "License");
   you may not use this file except in compliance with the License.
   You may obtain a copy of the License at

       http://www.apache.org/licenses/LICENSE-2.0

   Unless required by applicable law or agreed to in writing, software
   distributed under the License is distributed on an "AS IS" BASIS,
   WITHOUT WARRANTIES OR CONDITIONS OF ANY KIND, either express or implied.
   See the License for the specific language governing permissions and
   limitations under the License.

*/

#include <Arduino.h>
#include <Wire.h>
#include "MLX90640_I2C_Driver.h"

void MLX90640_I2CInit()
{

}

//Read a number of words from startAddress. Store into Data array.
//Returns 0 if successful, -1 if error
int MLX90640_I2CRead(uint8_t _deviceAddress, unsigned int startAddress, unsigned int nWordsRead, uint16_t *data)
{

  //Caller passes number of 'unsigned ints to read', increase this to 'bytes to read'
  uint16_t bytesRemaining = nWordsRead * 2;

  //It doesn't look like sequential read works. Do we need to re-issue the address command each time?

  uint16_t dataSpot = 0; //Start at beginning of array

  //Setup a series of chunked I2C_BUFFER_LENGTH byte reads
  while (bytesRemaining > 0)
  {
    Wire.beginTransmission(_deviceAddress);
    Wire.write(startAddress >> 8); //MSB
    Wire.write(startAddress & 0xFF); //LSB
    if (Wire.endTransmission(false) != 0) //Do not release bus
    {
      Serial.println("No ack read");
      return (0); //Sensor did not ACK
    }

    uint16_t numberOfBytesToRead = bytesRemaining;
    if (numberOfBytesToRead > I2C_BUFFER_LENGTH) numberOfBytesToRead = I2C_BUFFER_LENGTH;

    Wire.requestFrom((uint8_t)_deviceAddress, (uint8_t)numberOfBytesToRead);
    if (Wire.available())
    {
      for (uint16_t x = 0 ; x < numberOfBytesToRead / 2; x++)
      {
        //Store data into array
        data[dataSpot] = Wire.read() << 8; //MSB
        data[dataSpot] |= Wire.read(); //LSB

        dataSpot++;
      }
    }

    bytesRemaining -= numberOfBytesToRead;

    startAddress += numberOfBytesToRead / 2;
    
  }

  return (0); //Success
}

//Set I2C Freq, in kHz
//MLX90640_I2CFreqSet(1000) sets frequency to 1MHz
void MLX90640_I2CFreqSet(int freq)
{
  //i2c.frequency(1000 * freq);
  Wire.setClock((long)1000 * freq);
}

//Write two bytes to a two byte address
int MLX90640_I2CWrite(uint8_t _deviceAddress, unsigned int writeAddress, uint16_t data)
{
  Wire.beginTransmission((uint8_t)_deviceAddress);
  Wire.write(writeAddress >> 8); //MSB
  Wire.write(writeAddress & 0xFF); //LSB
  Wire.write(data >> 8); //MSB
  Wire.write(data & 0xFF); //LSB
  if (Wire.endTransmission() != 0)
  {
    //Sensor did not ACK
    Serial.println("Error: Sensor did not ack");
    return (-1);
  }

  uint16_t dataCheck;
  MLX90640_I2CRead(_deviceAddress, writeAddress, 1, &dataCheck);
  if (dataCheck != data)
  {
    //Serial.println("The write request didn't stick");
    return -2;
  }

  return (0); //Success
}

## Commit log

2024-07-31 修正按钮的功能
2024-08-02 修正模型，修改默认亮度
    [shell.STL, shell2040.STEP, shell_x1.STL]
2024-08-03 双线性插值
2024-08-22 充分发挥多核性能
2024-08-23 渲染模式切换，断电记忆
2024-08-23 用移位代替乘除法来提升性能
2024-10-10 更新了字体调节功能
    [on-off-button.SLDPRT]
